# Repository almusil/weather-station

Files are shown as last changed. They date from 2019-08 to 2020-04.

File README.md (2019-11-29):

# weather-station

## Node
### Bulding build container
Build node building container, under project root directory: 
```
docker build --rm \
 -t weather-station/node-build-image \
 -f ./docker/Dockerfile.node \
 .
 ```

New container is needed in case you want to update libopencm3 to the latest
or bump ARM GCC version.

### Running build
Build node source, under project root directory: 
```
./scripts/run-build-node.sh
```

Open the container shell without executing the build run: 
```
./scripts/run-build-node.sh --shell
```

## Schematic and board
Schematic and board design are under HW directory

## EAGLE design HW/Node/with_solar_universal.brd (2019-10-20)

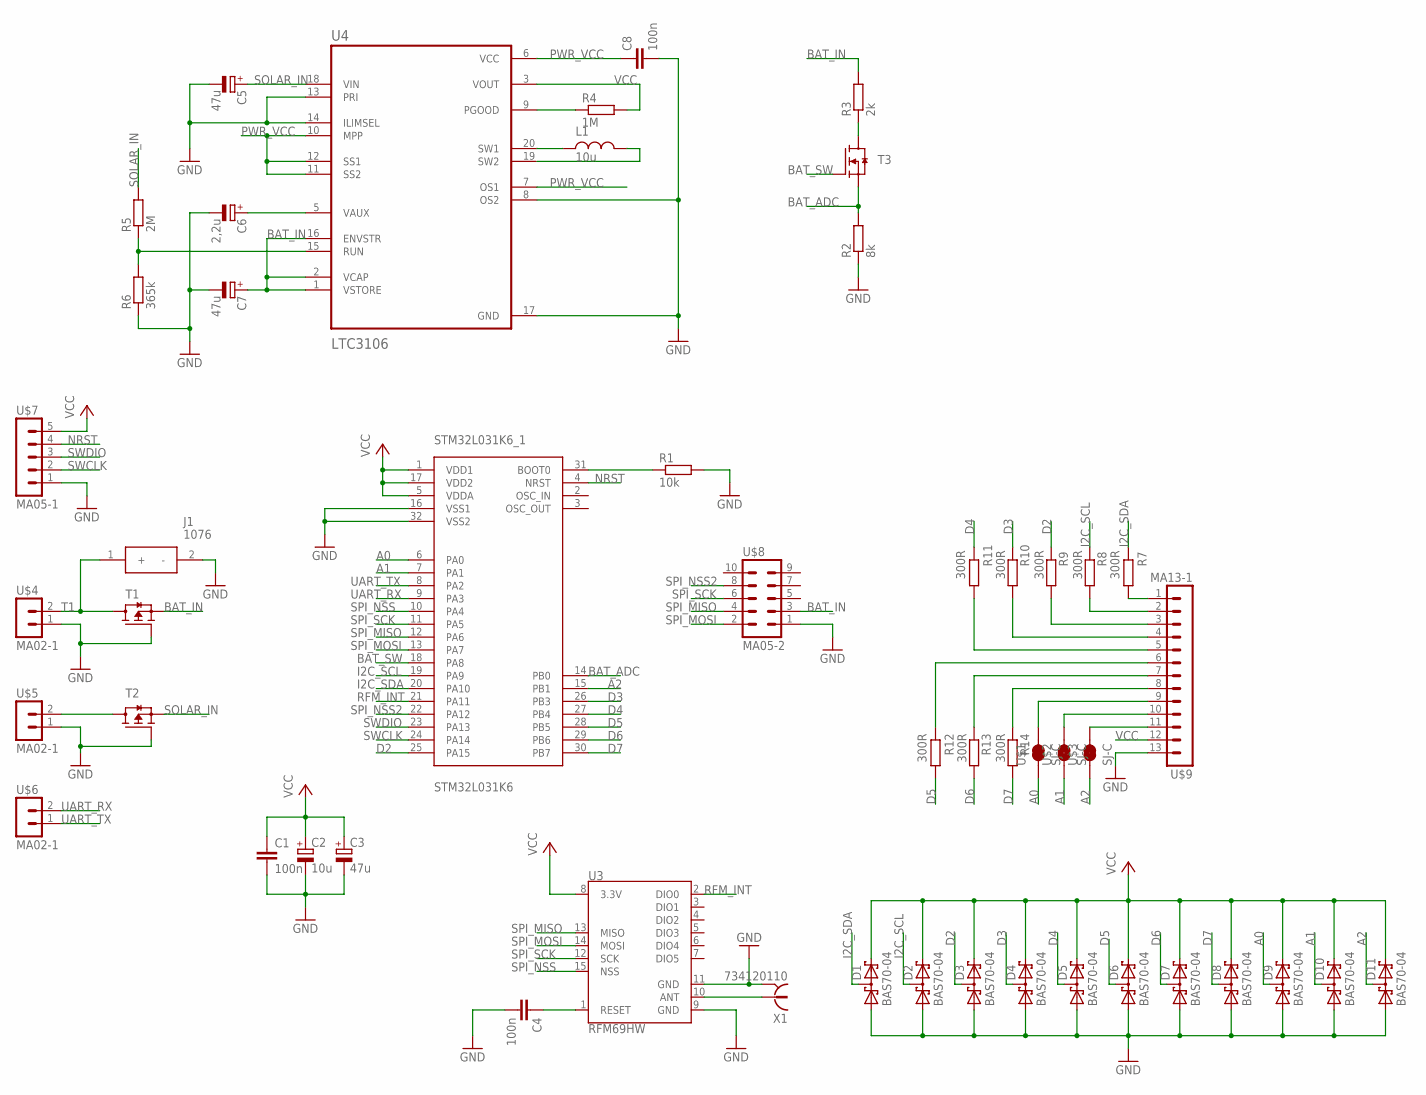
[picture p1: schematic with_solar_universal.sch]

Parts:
C1, C4, C8: 100n; C1206
C2: 10u; UD-4X5,8_NICHICON
C3, C5, C7: 47u; UD-4X5,8_NICHICON
C6: 2,2u; UD-4X5,8_NICHICON
D1, D2, D3, D4, D5, D6, D7, D8, D9, D10, D11: BAS70-04; SOT23
J1: 1076
L1: 10u; R1210
R1: 10k; R0805
R2: 8k; R0805
R3: 2k; R0805
R4: 1M; R0805
R5: 2M; R0805
R6: 365k; R0805
R7, R8, R9, R10, R11, R12, R13, R14: 300R; R0805
STM32L031K6_1: STM32L031K6; LQFP32-7X7
T1, T2: RTQ035P02HZG; SOT457R_PHILIPS
T3: RQ6E050AJTCR; SOT457R_PHILIPS
U3: RFM69HW; RFM69W-XXXS2
U4: LTC3106
U$1, U$2, U$3: SJ-C; R0805
U$4, U$5, U$6: MA02-1
U$7: MA05-1
U$8: MA05-2
U$9: MA13-1
X1: 734120110

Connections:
A0: D9.3 (K1A2), STM32L031K6_1.6 (PA0), U$1.1
A1: D10.3 (K1A2), STM32L031K6_1.7 (PA1), U$2.1
A2: D11.3 (K1A2), STM32L031K6_1.15 (PB1), U$3.1
BAT_ADC: R2.2, STM32L031K6_1.14 (PB0), T3.4 (S)
BAT_IN: C7.+, R3.2, T1.4 (S), U4.1 (VSTORE), U4.2 (VCAP), U4.16 (ENVSTR), U$8.3
BAT_SW: STM32L031K6_1.18 (PA8), T3.3 (G)
D2: D3.3 (K1A2), R9.2, STM32L031K6_1.25 (PA15)
D3: D4.3 (K1A2), R10.2, STM32L031K6_1.26 (PB3)
D4: D5.3 (K1A2), R11.2, STM32L031K6_1.27 (PB4)
D5: D6.3 (K1A2), R12.2, STM32L031K6_1.28 (PB5)
D6: D7.3 (K1A2), R13.2, STM32L031K6_1.29 (PB6)
D7: D8.3 (K1A2), R14.2, STM32L031K6_1.30 (PB7)
GND: C1.2, C2.-, C3.-, C4.2, C5.-, C6.-, C7.-, C8.2, D1.1 (A1), D2.1 (A1), D3.1 (A1), D4.1 (A1), D5.1 (A1), D6.1 (A1), D7.1 (A1), D8.1 (A1), D9.1 (A1), D10.1 (A1), D11.1 (A1), J1.2 (-), R1.2, R2.1, R6.1, STM32L031K6_1.16 (VSS1), STM32L031K6_1.32 (VSS2), T1.3 (G), T2.3 (G), U3.9 (GND), U3.11 (GND), U4.8 (OS2), U4.13 (PRI), U4.14 (ILIMSEL), U4.17 (GND), U$4.1 (2), U$5.1 (2), U$7.1, U$8.1, U$9.13, X1.S@1 (2), X1.S@2 (2), X1.S@3 (2)
I2C_SCL: D2.3 (K1A2), R8.2, STM32L031K6_1.19 (PA9)
I2C_SDA: D1.3 (K1A2), R7.2, STM32L031K6_1.20 (PA10)
unnamed: R1.1, STM32L031K6_1.31 (BOOT0)
unnamed: U3.10 (ANT), X1.1
unnamed: L1.1, U4.20 (SW1)
unnamed: L1.2, U4.19 (SW2)
unnamed: C6.+, U4.5 (VAUX)
unnamed: R4.1, U4.9 (PGOOD)
unnamed: R5.1, R6.2, U4.15 (RUN)
unnamed: R7.1, U$9.1
unnamed: R8.1, U$9.2
unnamed: C4.1, U3.1 (RESET)
unnamed: R9.1, U$9.3
unnamed: R10.1, U$9.4
unnamed: R11.1, U$9.5
unnamed: R12.1, U$9.6
unnamed: R13.1, U$9.7
unnamed: R14.1, U$9.8
unnamed: U$1.2, U$9.9
unnamed: U$2.2, U$9.10
unnamed: R3.1, T3.1 (D), T3.2 (D), T3.5 (D), T3.6 (D)
unnamed: U$3.2, U$9.11
NRST: STM32L031K6_1.4 (NRST), U$7.4
PWR_VCC: C8.1, U4.6 (VCC), U4.7 (OS1), U4.10 (MPP), U4.11 (SS2), U4.12 (SS1)
RFM_INT: STM32L031K6_1.21 (PA11), U3.2 (DIO0)
SOLAR_IN: C5.+, R5.2, T2.4 (S), U4.18 (VIN)
SPI_MISO: STM32L031K6_1.12 (PA6), U3.13 (MISO), U$8.4
SPI_MOSI: STM32L031K6_1.13 (PA7), U3.14 (MOSI), U$8.2
SPI_NSS: STM32L031K6_1.10 (PA4), U3.15 (NSS)
SPI_NSS2: STM32L031K6_1.22 (PA12), U$8.8
SPI_SCK: STM32L031K6_1.11 (PA5), U3.12 (SCK), U$8.6
SWCLK: STM32L031K6_1.24 (PA14), U$7.2
SWDIO: STM32L031K6_1.23 (PA13), U$7.3
T1: J1.1 (+), T1.1 (D), T1.2 (D), T1.5 (D), T1.6 (D), U$4.2 (3)
T2: T2.1 (D), T2.2 (D), T2.5 (D), T2.6 (D), U$5.2 (3)
UART_RX: STM32L031K6_1.9 (PA3), U$6.2 (3)
UART_TX: STM32L031K6_1.8 (PA2), U$6.1 (2)
VCC: C1.1, C2.+, C3.+, D1.2 (K2), D2.2 (K2), D3.2 (K2), D4.2 (K2), D5.2 (K2), D6.2 (K2), D7.2 (K2), D8.2 (K2), D9.2 (K2), D10.2 (K2), D11.2 (K2), R4.2, STM32L031K6_1.1 (VDD1), STM32L031K6_1.5 (VDDA), STM32L031K6_1.17 (VDD2), U3.8 (3.3V), U4.3 (VOUT), U$7.5, U$9.12

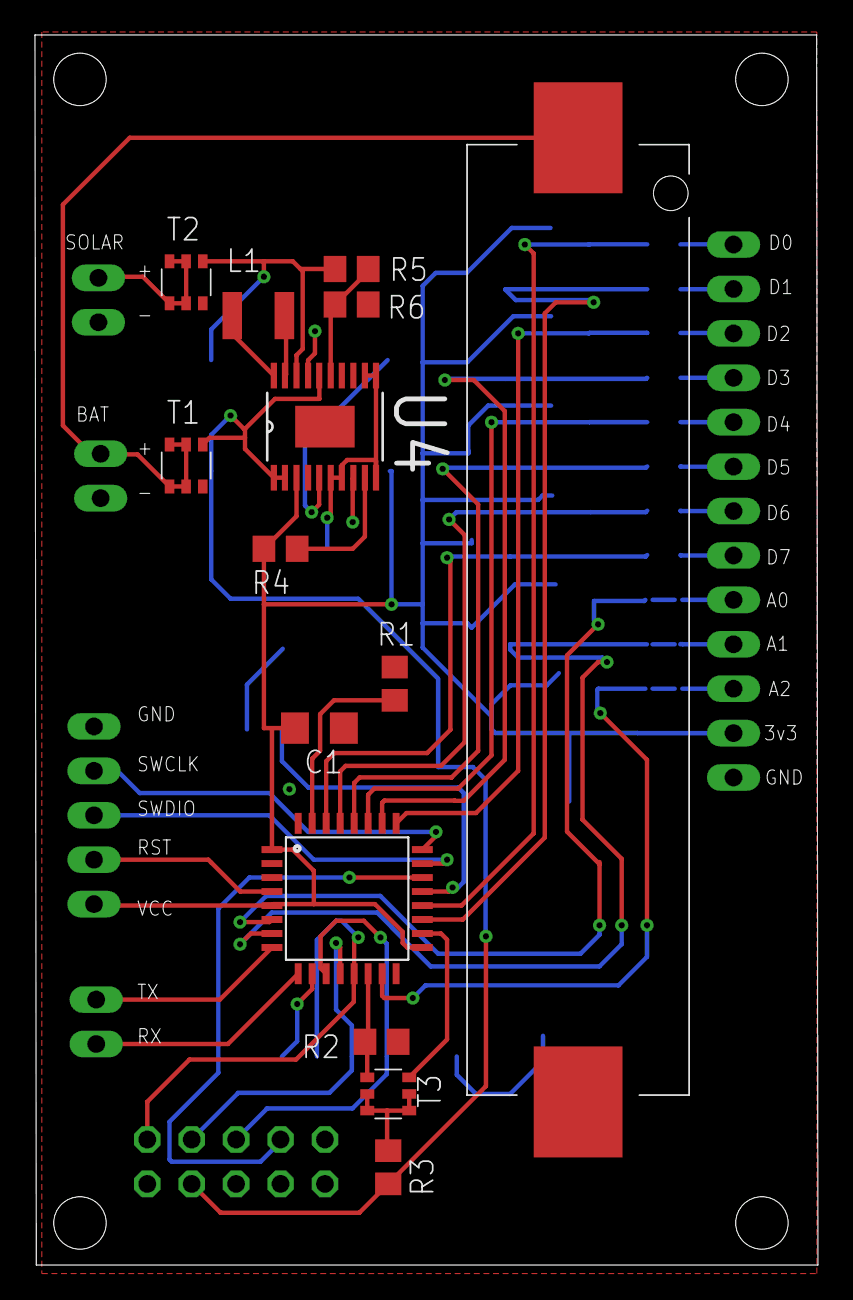
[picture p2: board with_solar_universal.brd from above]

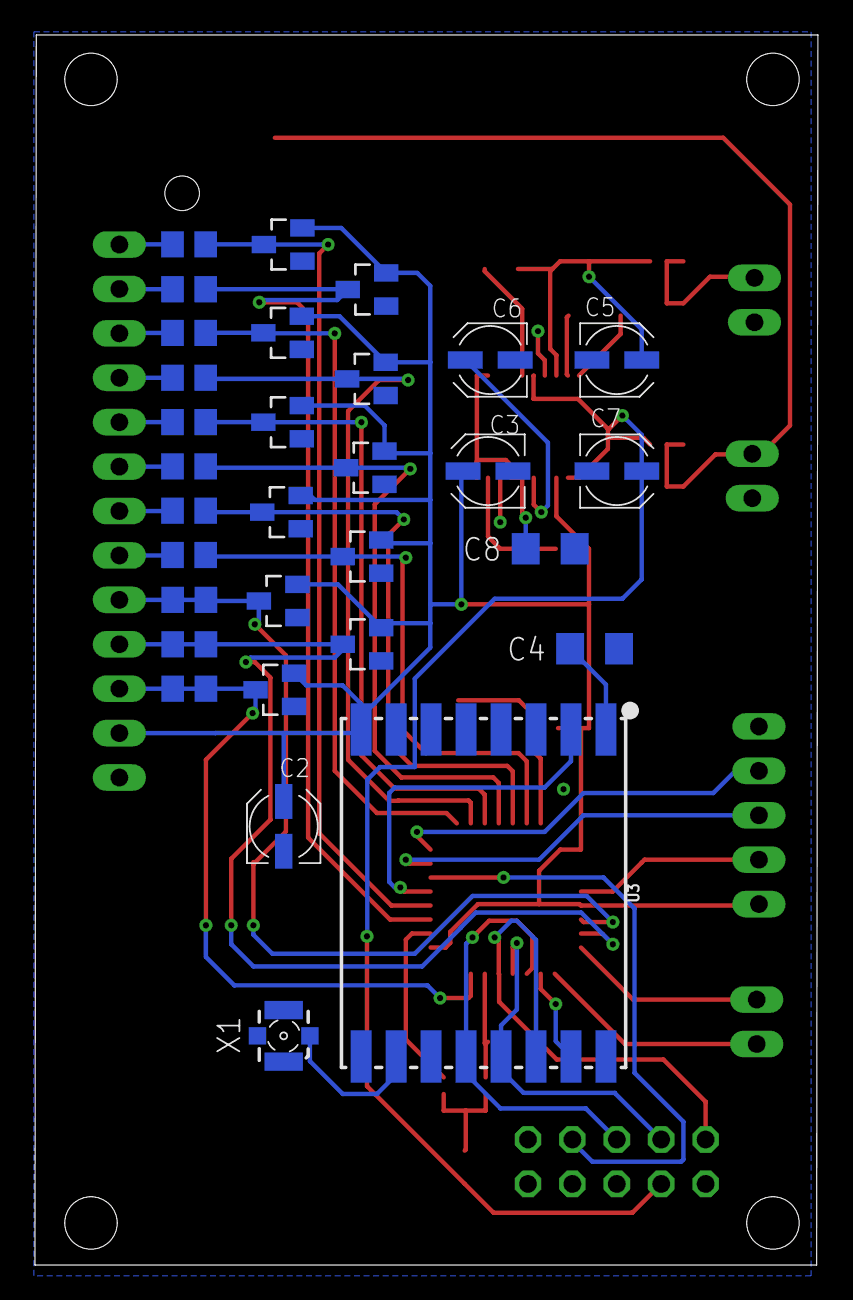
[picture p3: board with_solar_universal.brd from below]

Board: 2 copper layers, 44.8 x 70.3 mm, 51 parts (31 on the bottom side), 51 nets.

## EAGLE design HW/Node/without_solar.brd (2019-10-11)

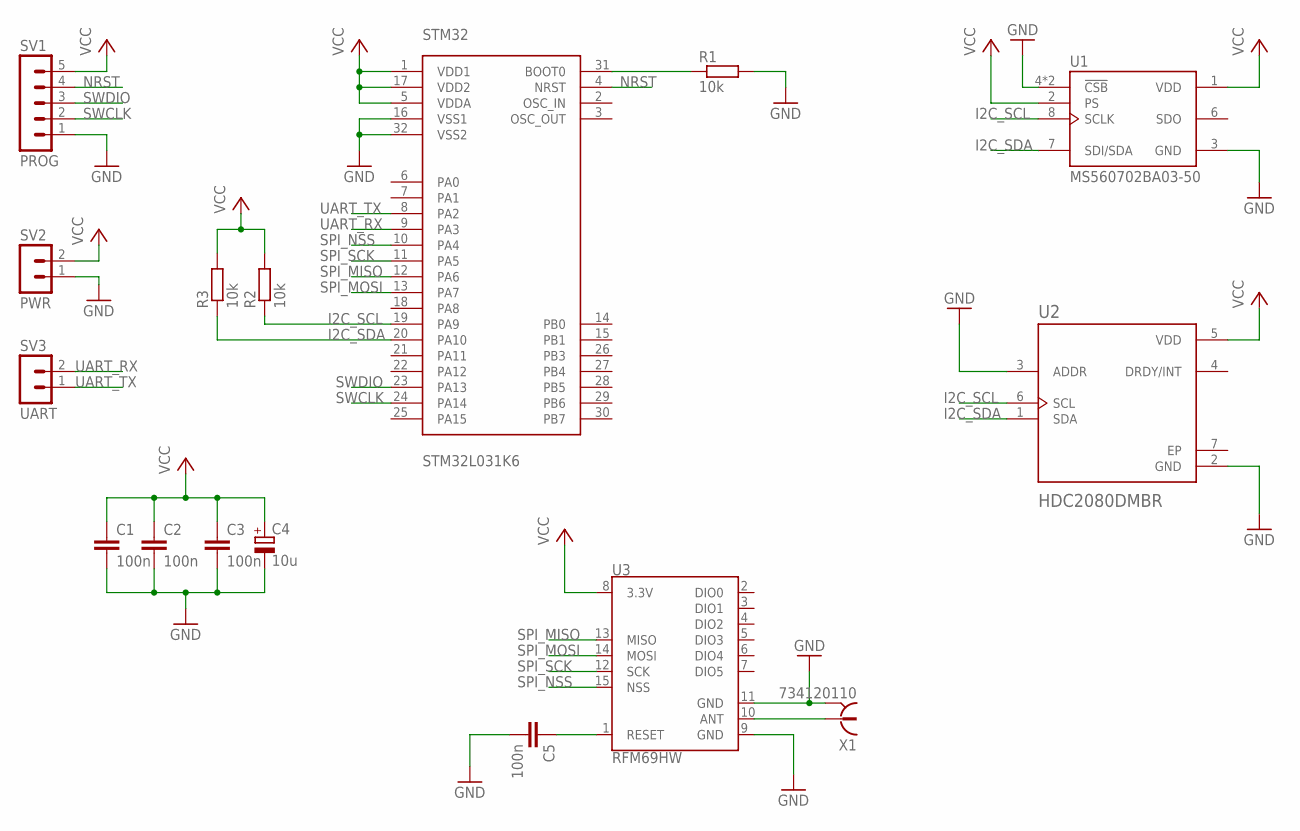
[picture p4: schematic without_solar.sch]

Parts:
C1, C2, C3, C5: 100n; C1206
C4: 10u; UD-4X5,8_NICHICON
R1, R2, R3: 10k; R0805
STM32: STM32L031K6; LQFP32-7X7
SV1: PROG; MA05-1
SV2: PWR; MA02-1
SV3: UART; MA02-1
U1: MS560702BA03-50; SON125P300X500X100-8N
U2: HDC2080DMBR; SON100P300X300X80-7N
U3: RFM69HW; RFM69W-XXXS2
X1: 734120110

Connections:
GND: C1.2, C2.2, C3.2, C4.-, C5.2, R1.2, STM32.16 (VSS1), STM32.32 (VSS2), SV1.1, SV2.1 (2), U1.3 (GND), U1.4 (!CSB), U1.5 (!CSB), U2.2 (GND), U2.3 (ADDR), U3.9 (GND), U3.11 (GND), X1.S@1 (2), X1.S@2 (2), X1.S@3 (2)
I2C_SCL: R2.1, STM32.19 (PA9), U1.8 (SCLK), U2.6 (SCL)
I2C_SDA: R3.1, STM32.20 (PA10), U1.7 (SDI/SDA), U2.1 (SDA)
unnamed: R1.1, STM32.31 (BOOT0)
unnamed: U3.10 (ANT), X1.1
unnamed: C5.1, U3.1 (RESET)
NRST: STM32.4 (NRST), SV1.4
RFM_INT: STM32.7 (PA1), U3.2 (DIO0)
SPI_MISO: STM32.12 (PA6), U3.13 (MISO)
SPI_MOSI: STM32.13 (PA7), U3.14 (MOSI)
SPI_NSS: STM32.10 (PA4), U3.15 (NSS)
SPI_SCK: STM32.11 (PA5), U3.12 (SCK)
SWCLK: STM32.24 (PA14), SV1.2
SWDIO: STM32.23 (PA13), SV1.3
UART_RX: STM32.9 (PA3), SV3.2 (3)
UART_TX: STM32.8 (PA2), SV3.1 (2)
VCC: C1.1, C2.1, C3.1, C4.+, R2.2, R3.2, STM32.1 (VDD1), STM32.5 (VDDA), STM32.17 (VDD2), SV1.5, SV2.2 (3), U1.1 (VDD), U1.2 (PS), U2.5 (VDD), U3.8 (3.3V)

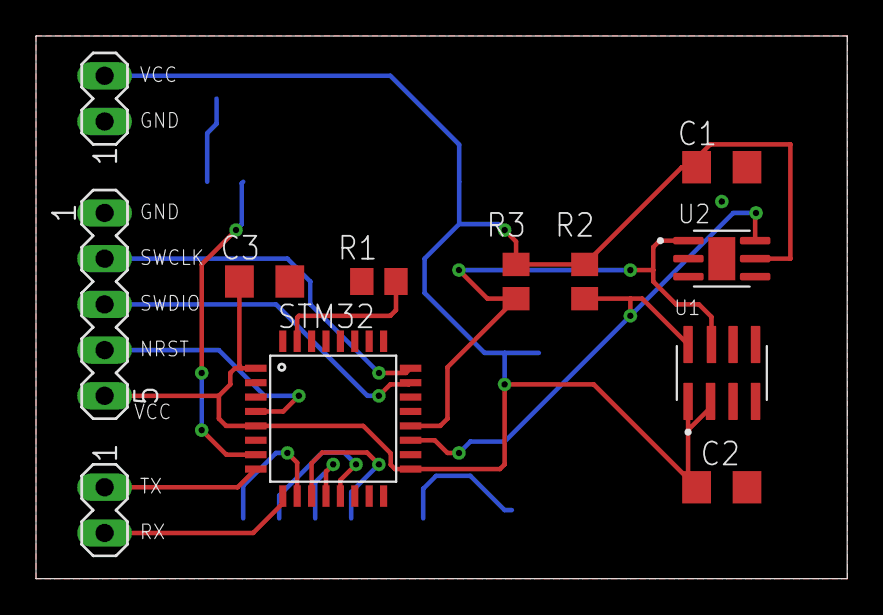
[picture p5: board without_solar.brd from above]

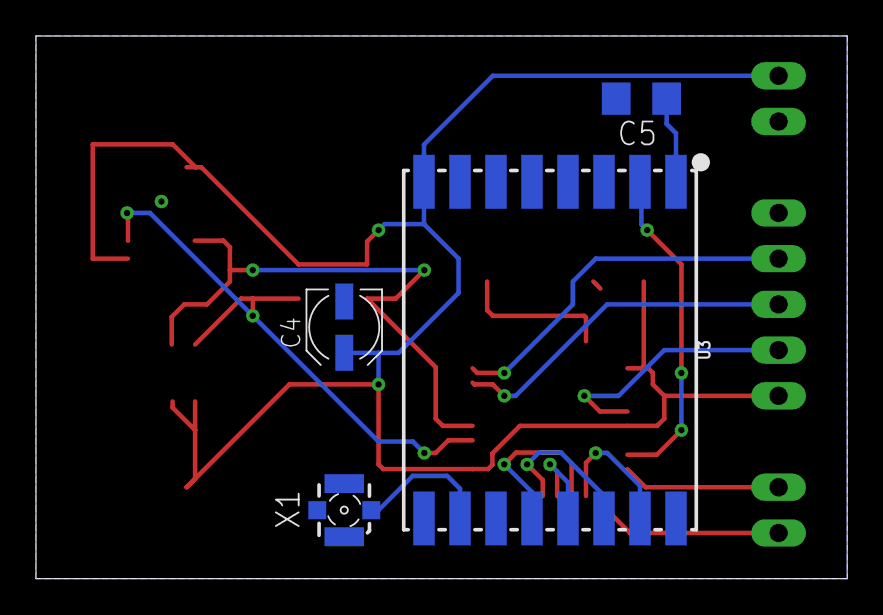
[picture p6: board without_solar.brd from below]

Board: 2 copper layers, 45.1 x 30.1 mm, 16 parts (4 on the bottom side), 17 nets.

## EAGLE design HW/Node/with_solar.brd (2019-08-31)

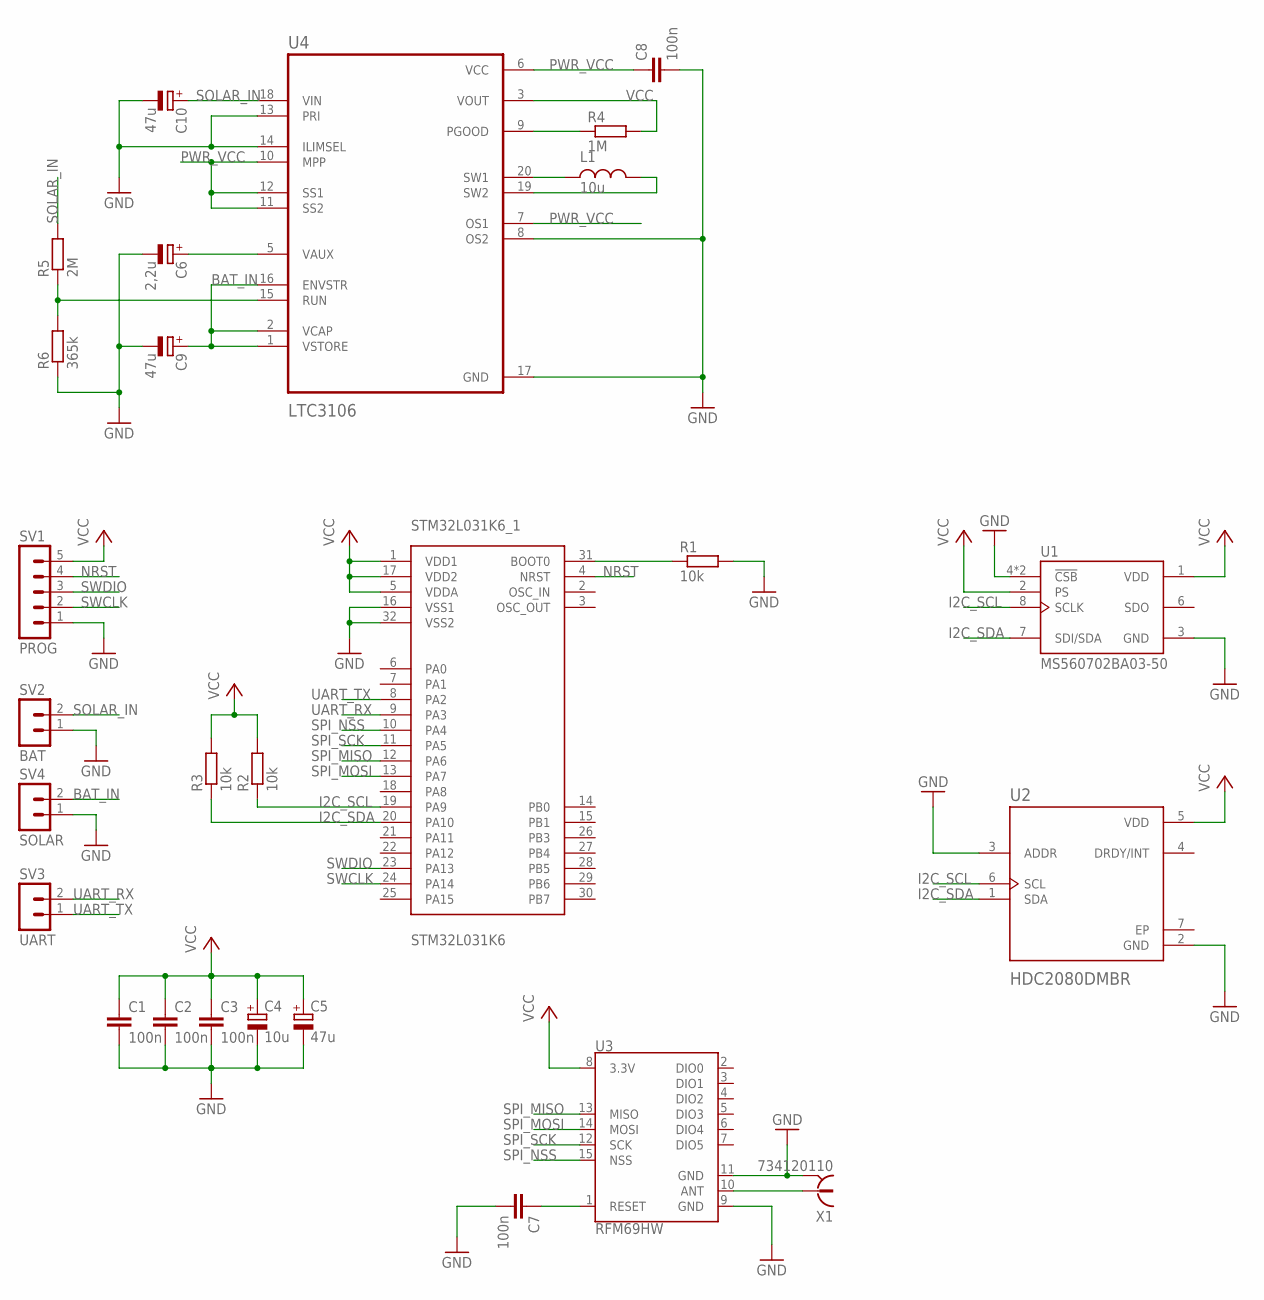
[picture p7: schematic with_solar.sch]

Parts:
C1, C2, C3, C7, C8: 100n; C1206
C4: 10u; UD-4X5,8_NICHICON
C5, C9, C10: 47u; UD-4X5,8_NICHICON
C6: 2,2u; UD-4X5,8_NICHICON
L1: 10u; R1210
R1, R2, R3: 10k; R0805
R4: 1M; R0805
R5: 2M; R0805
R6: 365k; R0805
STM32L031K6_1: STM32L031K6; LQFP32-7X7
SV1: PROG; MA05-1
SV2: BAT; MA02-1
SV3: UART; MA02-1
SV4: SOLAR; MA02-1
U1: MS560702BA03-50; SON125P300X500X100-8N
U2: HDC2080DMBR; SON100P300X300X80-7N
U3: RFM69HW; RFM69W-XXXS2
U4: LTC3106
X1: 734120110

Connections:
BAT_IN: C9.+, SV4.2 (3), U4.1 (VSTORE), U4.2 (VCAP), U4.16 (ENVSTR)
GND: C1.2, C2.2, C3.2, C4.-, C5.-, C6.-, C7.2, C8.2, C9.-, C10.-, R1.2, R6.1, STM32L031K6_1.16 (VSS1), STM32L031K6_1.32 (VSS2), SV1.1, SV2.1 (2), SV4.1 (2), U1.3 (GND), U1.4 (!CSB), U1.5 (!CSB), U2.2 (GND), U2.3 (ADDR), U3.9 (GND), U3.11 (GND), U4.8 (OS2), U4.13 (PRI), U4.14 (ILIMSEL), U4.17 (GND), X1.S@1 (2), X1.S@2 (2), X1.S@3 (2)
I2C_SCL: R2.1, STM32L031K6_1.19 (PA9), U1.8 (SCLK), U2.6 (SCL)
I2C_SDA: R3.1, STM32L031K6_1.20 (PA10), U1.7 (SDI/SDA), U2.1 (SDA)
unnamed: R1.1, STM32L031K6_1.31 (BOOT0)
unnamed: U3.10 (ANT), X1.1
unnamed: L1.1, U4.20 (SW1)
unnamed: L1.2, U4.19 (SW2)
unnamed: C6.+, U4.5 (VAUX)
unnamed: R4.1, U4.9 (PGOOD)
unnamed: R5.1, R6.2, U4.15 (RUN)
unnamed: C7.1, U3.1 (RESET)
NRST: STM32L031K6_1.4 (NRST), SV1.4
PWR_VCC: C8.1, U4.6 (VCC), U4.7 (OS1), U4.10 (MPP), U4.11 (SS2), U4.12 (SS1)
SOLAR_IN: C10.+, R5.2, SV2.2 (3), U4.18 (VIN)
SPI_MISO: STM32L031K6_1.12 (PA6), U3.13 (MISO)
SPI_MOSI: STM32L031K6_1.13 (PA7), U3.14 (MOSI)
SPI_NSS: STM32L031K6_1.10 (PA4), U3.15 (NSS)
SPI_SCK: STM32L031K6_1.11 (PA5), U3.12 (SCK)
SWCLK: STM32L031K6_1.24 (PA14), SV1.2
SWDIO: STM32L031K6_1.23 (PA13), SV1.3
UART_RX: STM32L031K6_1.9 (PA3), SV3.2 (3)
UART_TX: STM32L031K6_1.8 (PA2), SV3.1 (2)
VCC: C1.1, C2.1, C3.1, C4.+, C5.+, R2.2, R3.2, R4.2, STM32L031K6_1.1 (VDD1), STM32L031K6_1.5 (VDDA), STM32L031K6_1.17 (VDD2), SV1.5, U1.1 (VDD), U1.2 (PS), U2.5 (VDD), U3.8 (3.3V), U4.3 (VOUT)

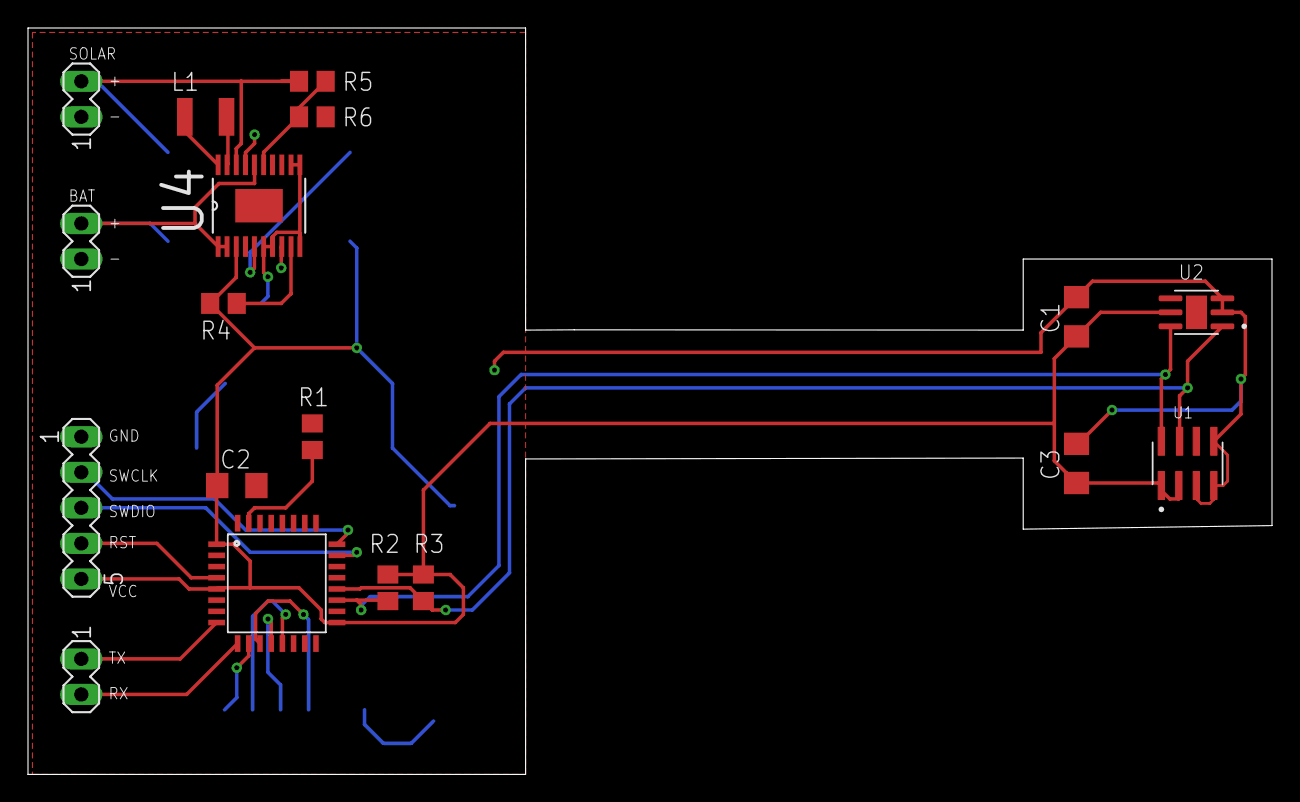
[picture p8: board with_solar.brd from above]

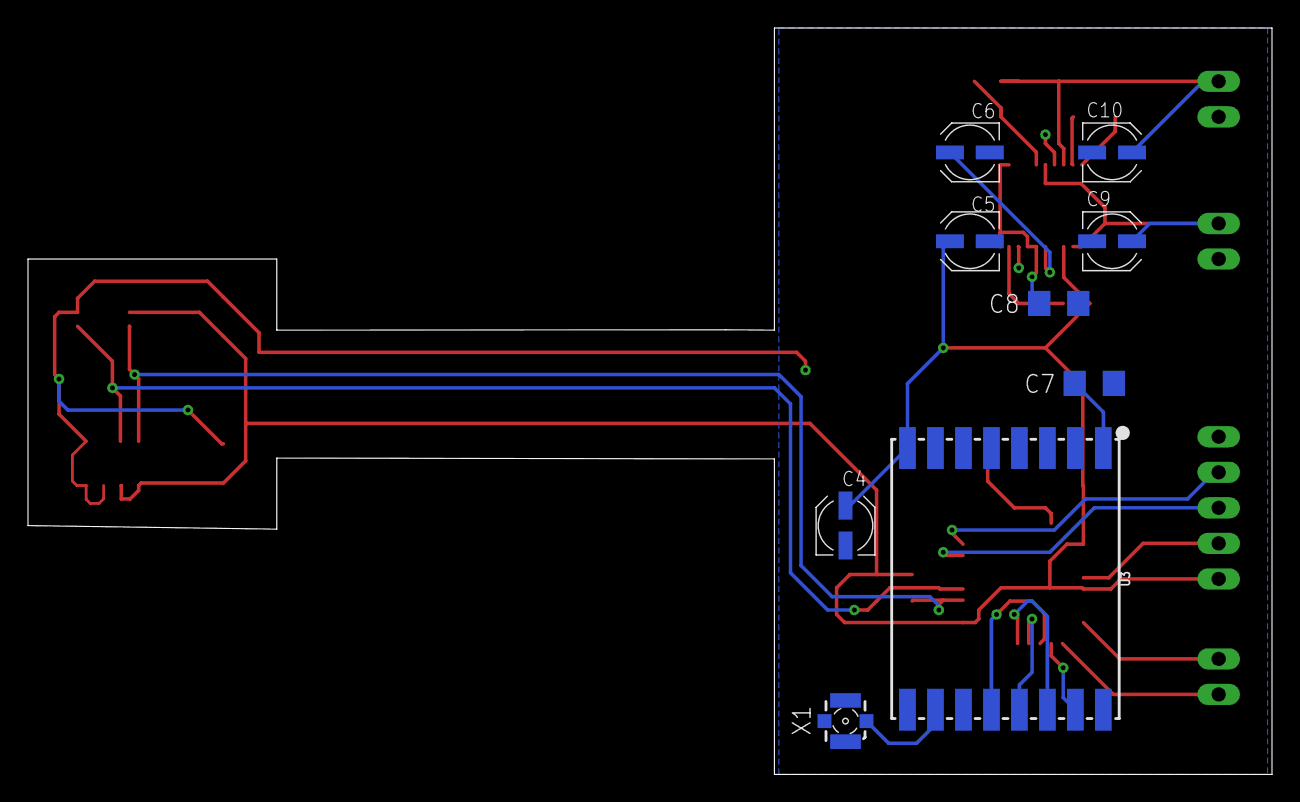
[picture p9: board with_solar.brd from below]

Board: 2 copper layers, 88.9 x 53.3 mm, 27 parts (9 on the bottom side), 24 nets.

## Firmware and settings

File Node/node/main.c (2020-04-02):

#include <libopencm3/stm32/rcc.h>
#include <libopencm3/stm32/gpio.h>
#include <libopencm3/stm32/pwr.h>

#include <periph/sys_tick.h>
#include <periph/rtc.h>
#include <periph/low_power.h>
#include <periph/spi.h>
#include <periph/usart.h>
#include <periph/adc.h>
#include <periph/gpio.h>
#include <periph/i2c.h>
#include <config.h>
#include <rfm69.h>
#include <bme280.h>

static struct config conf = {
        .sleep_time = 10,
        .dio_direction = 0x00,
        .dio_value = 0x00,
        .analog = BAT_CHANNEL
};

static void clock_setup(void);

static void gpio_setup(void);

static void setup(void);

static void deep_sleep(void);

static void before_sleep(void);

static void after_wakeup(void);

static bool packet_received(void);

static void update_config(void);

static void send_measured_data(void);

static void clock_setup() {
    //Setup clock to internal 16MHz
    rcc_osc_on(RCC_HSI16);
    rcc_wait_for_osc_ready(RCC_HSI16);

    //Enable SysClock to 16Mhz
    rcc_set_sysclk_source(RCC_HSI16);

    rcc_ahb_frequency = 16e6;
    rcc_apb1_frequency = 16e6;
    rcc_apb2_frequency = 16e6;

    rcc_periph_clock_enable(RCC_GPIOA);
    rcc_periph_clock_enable(RCC_GPIOB);
    rcc_periph_clock_enable(SPI_CLOCK);
    rcc_periph_clock_enable(RCC_PWR);
    rcc_periph_clock_enable(USART_CLOCK);
    rcc_periph_clock_enable(ADC_CLOCK);
    rcc_periph_clock_enable(I2C_CLOCK);
}


static void gpio_setup() {
    /*  SPI GPIO setup */
    gpio_mode_setup(SPI_PORT, GPIO_MODE_AF, GPIO_PUPD_NONE, SPI_SCK | SPI_MISO | SPI_MOSI);
    gpio_set_output_options(SPI_PORT, GPIO_OTYPE_PP, GPIO_OSPEED_VERYHIGH, SPI_SCK | SPI_MISO | SPI_MOSI);
    gpio_set_af(SPI_PORT, GPIO_AF0, SPI_SCK | SPI_MISO | SPI_MOSI);

    gpio_clear(RFM69_PORT, RFM69_NSS);
    gpio_mode_setup(RFM69_PORT, GPIO_MODE_OUTPUT, GPIO_PUPD_NONE, RFM69_NSS);
    gpio_set(RFM69_PORT, RFM69_NSS);

    /* I2C GPIO setup */
    gpio_mode_setup(I2C_PORT, GPIO_MODE_AF, GPIO_PUPD_NONE, I2C_SDA | I2C_SCL);
    /* I2C pins have to open-drain */
    gpio_set_output_options(I2C_PORT, GPIO_OTYPE_OD, GPIO_OSPEED_LOW, I2C_SDA | I2C_SCL);
    gpio_set_af(I2C_PORT, GPIO_AF1, I2C_SDA | I2C_SCL);

    /* RFM69 interrupt setup */
    gpio_mode_setup(RFM69_PORT, GPIO_MODE_INPUT, GPIO_PUPD_PULLDOWN, RFM69_INT);

    /* USART GPIO setup */
    gpio_mode_setup(USART_PORT, GPIO_MODE_AF, GPIO_PUPD_NONE, USART_TX | USART_RX);
    gpio_set_af(USART_PORT, GPIO_AF4, USART_TX | USART_RX);

    /* ADC GPIO setup */
    gpio_mode_setup(ADC_PORT1, GPIO_MODE_ANALOG, GPIO_PUPD_NONE, A0 | A1);
    gpio_mode_setup(ADC_PORT2, GPIO_MODE_ANALOG, GPIO_PUPD_NONE, BAT_ADC | A2);

    /* Battery switch */
    gpio_mode_setup(SW_PORT, GPIO_MODE_OUTPUT, GPIO_PUPD_NONE, SW_PIN);
    gpio_clear(SW_PORT, SW_PIN);
}

static void setup() {
    clock_setup();
    gpio_setup();
    sys_tick_setup();
    spi_setup();
    rtc_setup();
    usart_setup(USART_SPEED);
    rfm69_setup();
    adc_setup();
    i2c_setup();
    bme_setup();
    gpio_dio_setup(conf.dio_direction, conf.dio_value);
}

static void deep_sleep() {
    before_sleep();
    enter_stop_mode();
    after_wakeup();
}

static void before_sleep() {
    printf("Going to sleep!\n");
    sys_tick_disable();
    usart_interrupt_disable();
    rtc_wakeup_setup(conf.sleep_time);
    rfm69_sleep();
    spi_lib_disable();
    i2c_disable();
}

static void after_wakeup() {
    rtc_disable();
    sys_tick_enable();
    usart_interrupt_enable();
    spi_lib_enable();
    rfm69_wakeup();
    i2c_enable();
    printf("Back from sleep!\n");
}

static bool packet_received() {
    uint64_t now = get_millis();
    bool done = rfm69_receive_done();
    while (!done && get_millis() - now < CONFIG_TIMEOUT) {
        done = rfm69_receive_done();
    }
    printf("Received %d!\n", done);
    return done;
}

static void update_config() {
    struct rfm69_packet packet = {0};
    rfm69_get_data(&packet);
    if (packet.sender_id == GATEWAY_ADDR &&
        packet.target_id == NODE_ADDR &&
        packet.data_len == CONFIG_LENGTH + 1 &&
        packet.data_buffer[0] == PACKET_CONFIG) {
        // Update conf
        conf.sleep_time = (packet.data_buffer[2] << 8) | packet.data_buffer[1];
        conf.dio_direction = packet.data_buffer[3];
        conf.dio_value = packet.data_buffer[4];
        conf.analog = (packet.data_buffer[5] & 0x07) | BAT_CHANNEL;

        // Call gpio_setup
        gpio_dio_setup(conf.dio_direction, conf.dio_value);
        printf("Got new config!\n");
    }
}

static void send_measured_data() {
    printf("Sending measured data!\n");
    union packet_t packet = {0};
    uint16_t adc[4] = {0};

    bme_start_measurement();
    gpio_set(SW_PORT, SW_PIN);
    adc_convert(conf.analog, adc, 4);
    gpio_clear(SW_PORT, SW_PIN);

    if (conf.analog & A2_CHANNEL) {
        // Swap A2 and BAT adc data
        uint16_t tmp = adc[2];
        adc[2] = adc[3];
        adc[3] = tmp;
    }

    packet.data.packet_type = PACKET_DATA;
    packet.data.gpio_value = read_gpio_value();

    for (uint8_t i = 0; i < 4; i++) {
        packet.data.adc_value[i] = adc[i];
    }

    while (!bme_measure_done());

    packet.data.temperature = bme_get_temp();
    packet.data.pressure = bme_get_pressure();

    packet.data.humidity = bme_get_humidity();


    for (uint8_t i = 0; i < ACK_RETRY_COUNT; i++) {
        rfm69_send(GATEWAY_ADDR, &packet.bytes, sizeof(union packet_t), true);
        uint64_t now = get_millis();
        bool done = rfm69_ack_received(GATEWAY_ADDR);
        while (!done && get_millis() - now < ACK_TIMEOUT) {
            done = rfm69_ack_received(GATEWAY_ADDR);
        }
        if (done) {
            printf("Got ACK!\n");
            break;
        }
    }
}

int main(void) {
    setup();
    delay(1000);
    while (1) {
        uint8_t buffer = {PACKET_CONFIG};
        rfm69_send(GATEWAY_ADDR, &buffer, 1, false);
        bool new_packet = packet_received();
        if (new_packet) {
            update_config();
        }
        send_measured_data();
        deep_sleep();
    }
}

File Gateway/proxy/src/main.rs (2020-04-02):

#![recursion_limit = "256"]
#[macro_use]
extern crate failure;
#[macro_use]
extern crate log;

use crate::error::Result;
use crate::proxy::Proxy;
use crate::util::{Sender, Shared, CONF_PATH, LOG_MODULE_IGNORE, LOG_PATH, LOG_TIME_FORMAT};
use async_std::sync::{Arc, Mutex};
use async_std::task::block_on;
use futures::channel::mpsc;
use futures::SinkExt;
use simplelog::{ConfigBuilder, LevelFilter, WriteLogger};
use std::fs::File;

mod config;
mod data;
mod error;

#[macro_use]
mod util;
mod home_assistant;
mod proxy;
mod radio;
mod vutbr;

#[async_std::main]
async fn main() {
    let result = run_main().await;
    if let Err(err) = result {
        eprintln!("{}", err);
        error!("{:?}", err);
    }
}

async fn run_main() -> Result<()> {
    let config = ConfigBuilder::new()
        .set_location_level(LevelFilter::Error)
        .set_time_format_str(LOG_TIME_FORMAT)
        .add_filter_ignore_str(LOG_MODULE_IGNORE)
        .build();
    let _ = WriteLogger::init(LevelFilter::Debug, config, File::create(LOG_PATH)?);
    let (s, r) = mpsc::unbounded();
    let sender = new_shared!(s);
    configure_ctrlc_handler(sender);

    let mut proxy = Proxy::new(CONF_PATH, r).await?;
    proxy.main_loop().await?;

    info!("Exiting");
    Ok(())
}

fn configure_ctrlc_handler(shared_sender: Shared<Sender<bool>>) {
    ctrlc::set_handler(move || {
        info!("Got CTRL+C");
        let mut sender = block_on(shared_sender.lock());
        block_on(sender.send(true)).unwrap();
    })
    .unwrap();
}

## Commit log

2019-08-31 HW: Add Node schematic and board design
    [with_solar.brd, with_solar.sch, without_solar.brd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]
2019-09-21 Node, rfm69: Fix SPI communication
    [main.c]
2019-10-04 Node, rfm69: Add interrupt routine for rfm69 interrupts
2019-10-04 Node, SPI: Add method to enable/disable SPI
    Use enable after wakeup and disable before sleep to save most of the
    during low power.
2019-10-04 Node, rfm69: Add current state to track our current settings
2019-10-04 Node, rfm69: Add send and receive functionality
    Add functions required to send and receive payload
    that is compatible with LowPowerLab Arduino library[1].
    [1] https://github.com/LowPowerLab/RFM69
2019-10-11 HW: Update node schematic and board
    [with_solar.sch, with_solar_universal.brd, with_solar_universal.sch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]
2019-10-20 HW: Update node schematic and board
    - Use different input protection.
    - Add current limiting resistor.
    - Add AAA battery holder.
    [with_solar_universal.brd, with_solar_universal.sch]
2019-10-28 Node, rfm69: Fix interrupt pin and handler
    Interrupt for rfm69 moved to pin GPIOA11. We need to shift the EXTI
    and NVIC accordingly.
2019-10-28 Node: Add support for ADC defined according to schematic
2020-01-05 Node: Remove I2C files
2020-01-05 Gateway: Add better error handling and error progataion
    [error.rs, main.rs, radio.rs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]
2020-04-02 Node: Some minor fixes
    - Create proper .gdbinit file to upload program with Black
    Magic Probe
    - Fix UART RX pin assigment
    - Add sleep before program starts in order to make it
    easier for GDB to break program before sleep.
    - Swap BAT and A2 values before sending them
    - Fix config value for ADC
    [main.c]
2020-04-02 Gateway: Update pin management
    Update Linux Embedded Hal pin management according to
    lastest changes.
2020-04-02 Gateway: Wait for a proper rfm interrupt
    To prevent 100% CPU load add loop that will wait
    for the proper receive interrupt.
    [radio.rs, util.rs]
2020-04-02 Node: Fix reading of battery voltage
    [main.c]
2020-04-02 Gateway: Update battery template to compute exact voltage
2020-04-02 Node: Add I2C periph library
2020-04-02 Gateway: Add reporting of weather sensor
2020-04-02 Gateway: Update rfm69 dependency and error
    [error.rs]

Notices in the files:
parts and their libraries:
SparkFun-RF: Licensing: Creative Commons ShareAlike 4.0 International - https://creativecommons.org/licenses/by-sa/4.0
